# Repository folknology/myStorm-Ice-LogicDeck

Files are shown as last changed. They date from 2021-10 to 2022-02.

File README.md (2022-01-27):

# Ice LogicDeck 
The very first myStorm [Tile](https://github.com/folknology/Tiles) based logic deck, designed around the combination of a powerful STM32 F7 microcontroller fused with a fully configurable Lattice Ice40Hx FPGA.
This forms a modular, heterogeneous embedded development system, it is very much WIP. We will add more documentation soon, you can follow the [live](https://www.twitch.tv/folknology) streaming [narrative](https://www.youtube.com/playlist?list=PLXS9jyX9czzqn4HU2mEmoEFxpgIv1Dvy7) as we develop it, you can follow the evolving [documentation](https://folknology.github.io/myStorm-Ice-LogicDeck/).

#### The 'Deck' based solution is formed by combining multiple [Tiles](https://github.com/folknology/Tiles) and the Ice Logic board carrier
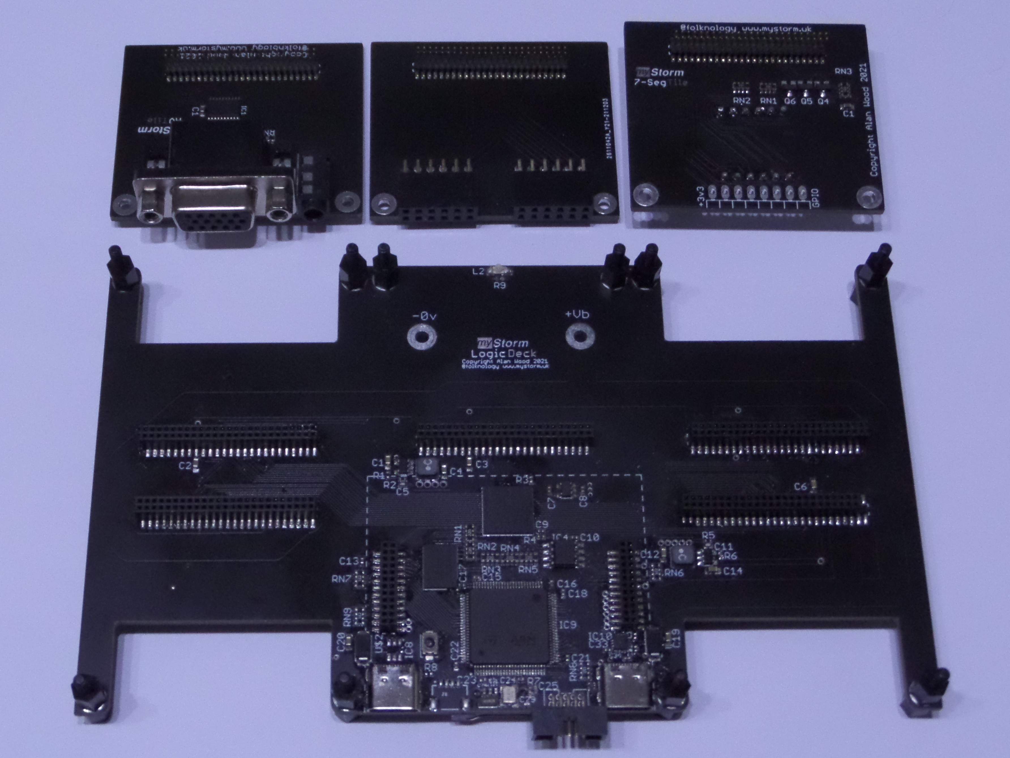
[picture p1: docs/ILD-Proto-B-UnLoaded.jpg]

#### Together these form an Ice LogicDeck solution
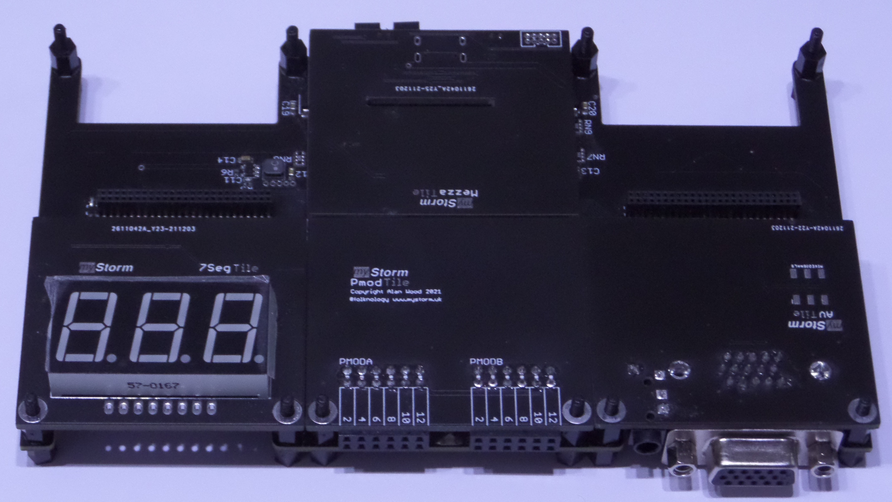
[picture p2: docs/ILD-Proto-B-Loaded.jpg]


### Hardware, development, tooling and software
- [Hardware sources](https://github.com/folknology/myStorm-Ice-LogicDeck/tree/main/Hardware)
- [Firmware sources](https://github.com/folknology/BlackCrab)
- [Examples & board support](https://github.com/folknology/myStorm-Ice-LogicDeck/tree/main/HDL)
- [FPGA HDL/Synthesis, PNR, simulation and formal - Yosys OSS cad suite](https://github.com/YosysHQ/oss-cad-suite-build)

### Further information
- [Tiles](https://github.com/folknology/Tiles)
- [Documentation](https://folknology.github.io/myStorm-Ice-LogicDeck/)
- [Discuss LogicDecks on Discord](https://discord.gg/RCGcgbQNZK)

### OpenSource Design
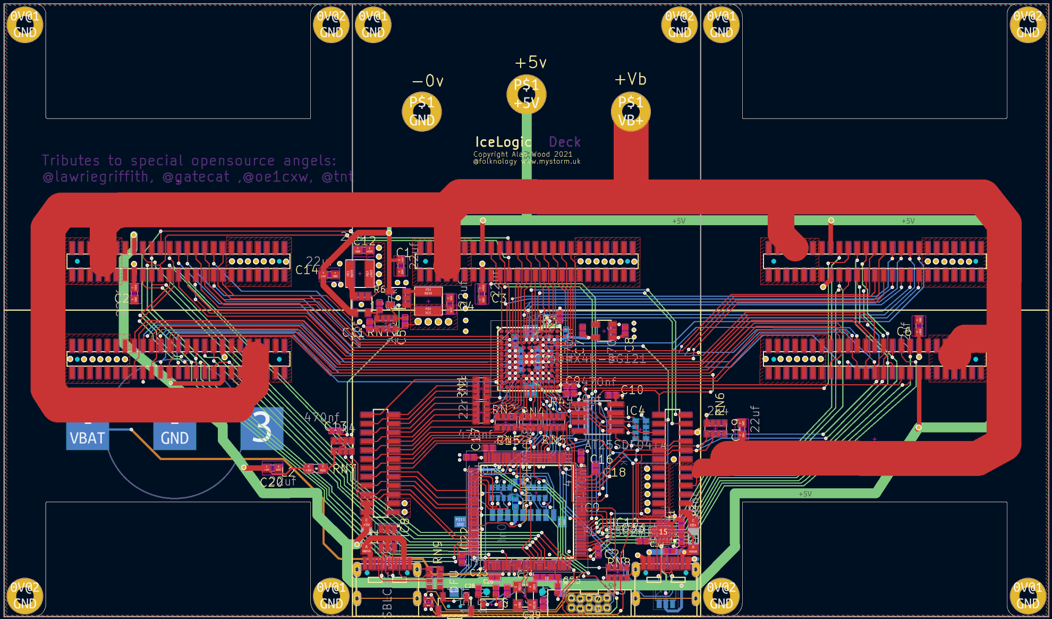
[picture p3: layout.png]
LogicDeck Layout

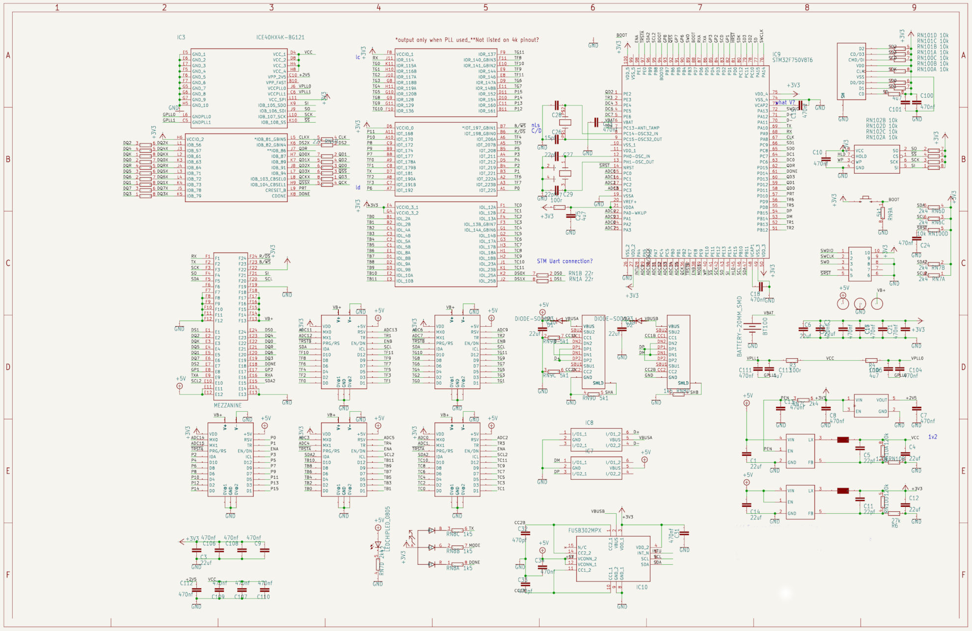
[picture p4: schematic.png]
LogicDeck Schematic


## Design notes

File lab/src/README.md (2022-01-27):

# Lab Notes - Introductions

The documentation is currently under construction and is being developed along with a [live](https://www.twitch.tv/folknology) streaming [narrative](https://www.youtube.com/playlist?list=PLXS9jyX9czzqn4HU2mEmoEFxpgIv1Dvy7) it is very much a work in progress, you can already find some interesting stuff in the examples section.

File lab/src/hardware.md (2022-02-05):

# Ice LogicDeck Hardware
The Ice LogicDeck (ILD) Hardware consists of modular tiles fitted to the main carrier board as required for the given development project. Onboard the main ILD carrier board are the Microcontroller, the FPGA some SPI Flash and connectors.

## Connectivity
The ILD has two Usb connectors, the first is a Usb-C configured as a USB CDC serial device. This can allow programming of the microcontroller, FPGA and flash, along with uart and monitoring features depending on the required mode.

There is a second Usb-C (Usb-PD) Connector which operates as a high Power over Usb 
delivery system operating from 5 to 20 volts in order to be able to power a large range of modular tiles from simple led drivers through to small motor and power-train devices. An auxiliary power supply scheme is also  provided for the more extreme power delivery requirements across the tiles.

## Operating Modes
Mode selection is achieved via the 'Mode' button, if depressed on power up it switches the device into Usb-DFU mode which enables the firmware to be updated from the PC host over Usb. Normal startup places the device into _Development mode_. In development mode the device intelligently listens to Usb traffic for new deck application, FPGA updates whilst concurrently relaying monitor, logging and error information.

A third _Advanced mode_ can be entered pressing the mode button during normal operation. This mode enables additional sub-command modes including _terminal_ , _test_ and  _flash_ for making things permanent or adding ROM data etc.. one can switch back to development mode simple by pressing the mode button once more.

## Status and feedback
There is an RGB led on board which can provide feedback and status of the board's mode and operation. In normal mode this is unlit. if and application or FPGA image is uploaded it will change to red and extinguish on successful completion. If it remains red it will normally be due to either a hardware fault or bad FPGA synthesis. If the mode changes it will illuminate green and change to amber during programing and back to green afterwards, again if it remains amber it will likely be a fault. A third state is possible when the FPGA synthesis drives the blue part of the led for example in a blinky test, the colour will the blink between the either blue and off or blue and the mode colour probably blue and turquoise.

There is also a 1.27mm pitch 10pin, Arm SWD debug socket adjacent to the Usb-PD if you need to debug what is running on the Microcontroller.

In addition to the modular tiles there is an optional Mezzanine Tile which can expand the ILD to add useful features like extra RAM, flash, lcd display and Wi-Fi among other things, check out the [Mezzanine](./mezzanine.md) section for more information of these options.

Setting up Ice LogicDeck - Drivers and firmware:
- [DFU](./dfu_util.md)
- [USB-CDC](./usbcdc.md)
- [Power Delivery](./usbpd.md)

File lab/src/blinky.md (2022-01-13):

# Blinky

## Simple Amaranth blinky using the onboard LED
Simple led blinky example using the blue part of the 
rgb led on the Ice LogicDeck.
```python
{{#include ../../HDL/Amaranth_Examples/Blinky.py}}
```

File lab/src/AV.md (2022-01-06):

# Audio and Video Tile

## VGA VGA Driver and Timings AHDL
```python
{{#include ../../HDL/Amaranth_Examples/Tiles/AAVC_tile.py}}
```

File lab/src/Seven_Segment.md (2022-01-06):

# Seven Segment Tile

## Here is the Top level AHDL Seven_segment.py
Shown below is the Tile example class example we derived from the BlackIce Mx nMigen [examples](https://github.com/lawrie/blackicemx_nmigen_examples/tree/main/seven_segment) for the seven segment tile.
```python
{{#include ../../HDL/Amaranth_Examples/Seven_Segment.py}}
```
## The Seven Segment Tile Driver
The tile driver abstracts the tile resource pinouts handling the low level Hex->7-segment encoding.
```python
{{#include ../../HDL/Amaranth_Examples/Tiles/seven_seg_tile.py}}
```

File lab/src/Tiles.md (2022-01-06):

# Tiles 

## Led test example
We start with a standard tile resource abstraction to work with a protoboard that I have added 12 LEDS t0. We then run some basic Amaranth python HDL to exercise the leds

```python
from amaranth import *
from amaranth.build import *
from IceLogicDeck import *

leds12_tile = [
    Resource("leds12", 0,
            Subsignal("leds", Pins("1 2 3 4 5 6 7 8 9 10 11 12", dir="o", conn=("tile",2)), Attrs(IO_STANDARD="SB_LVCMOS")))
]

class LEDTileTest(Elaboratable):
    def elaborate(self, platform):
        leds12 = Cat([l for l in platform.request("leds12")])
        timer = Signal(38)

        m = Module()
        m.d.sync += timer.eq(timer + 1)
        m.d.comb += leds12.eq(timer[-15:-1])
        return m

if __name__ == "__main__":
    platform = IceLogicDeckPlatform()
    platform.add_resources(leds12_tile)
    platform.build(LEDTileTest(), do_program=True)
```

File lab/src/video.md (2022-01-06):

# Video
## How a VGA frame is divided
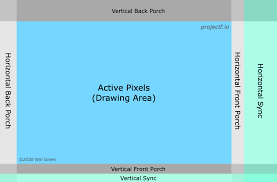
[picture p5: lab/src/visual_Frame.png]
frame

## The VGA Signals
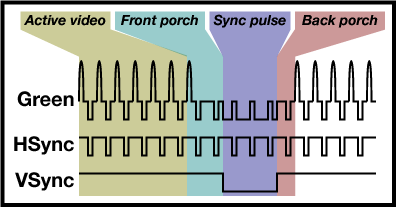
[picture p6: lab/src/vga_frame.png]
signal

## VGA Example AHDL
```python
{{#include ../../HDL/Amaranth_Examples/Audio_Video.py}}
```
## VGA VGA Driver and Timings AHDL
```python
{{#include ../../HDL/Amaranth_Examples/Tiles/vga.py}}
```
[Code we ported from Lawrie](https://github.com/lawrie/blackicemx_nmigen_examples/tree/main/simple_vga) which in turn was built on 
[Guztech's VGA for ULX3s](https://github.com/GuzTech/ulx3s-nmigen-examples/tree/master/dvi)

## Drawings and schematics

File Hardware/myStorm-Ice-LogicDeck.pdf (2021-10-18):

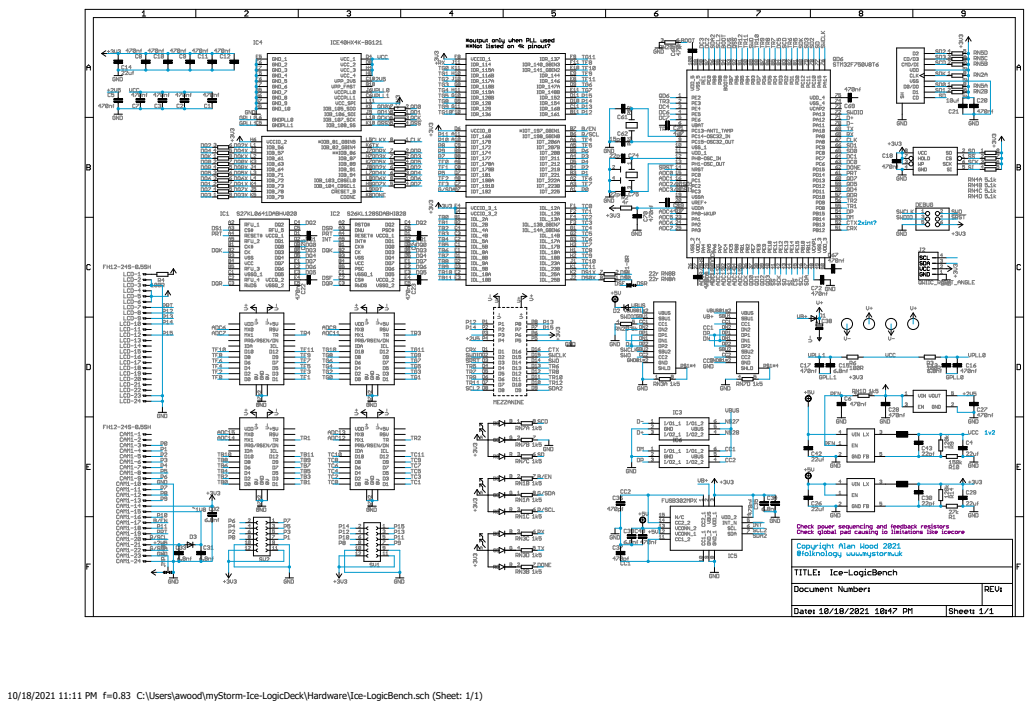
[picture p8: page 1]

10/18/2021 11:11 PM f=0.83 C:\Users\awood\myStorm-Ice-LogicDeck\Hardware\Ice-LogicBench.sch (Sheet: 1/1)

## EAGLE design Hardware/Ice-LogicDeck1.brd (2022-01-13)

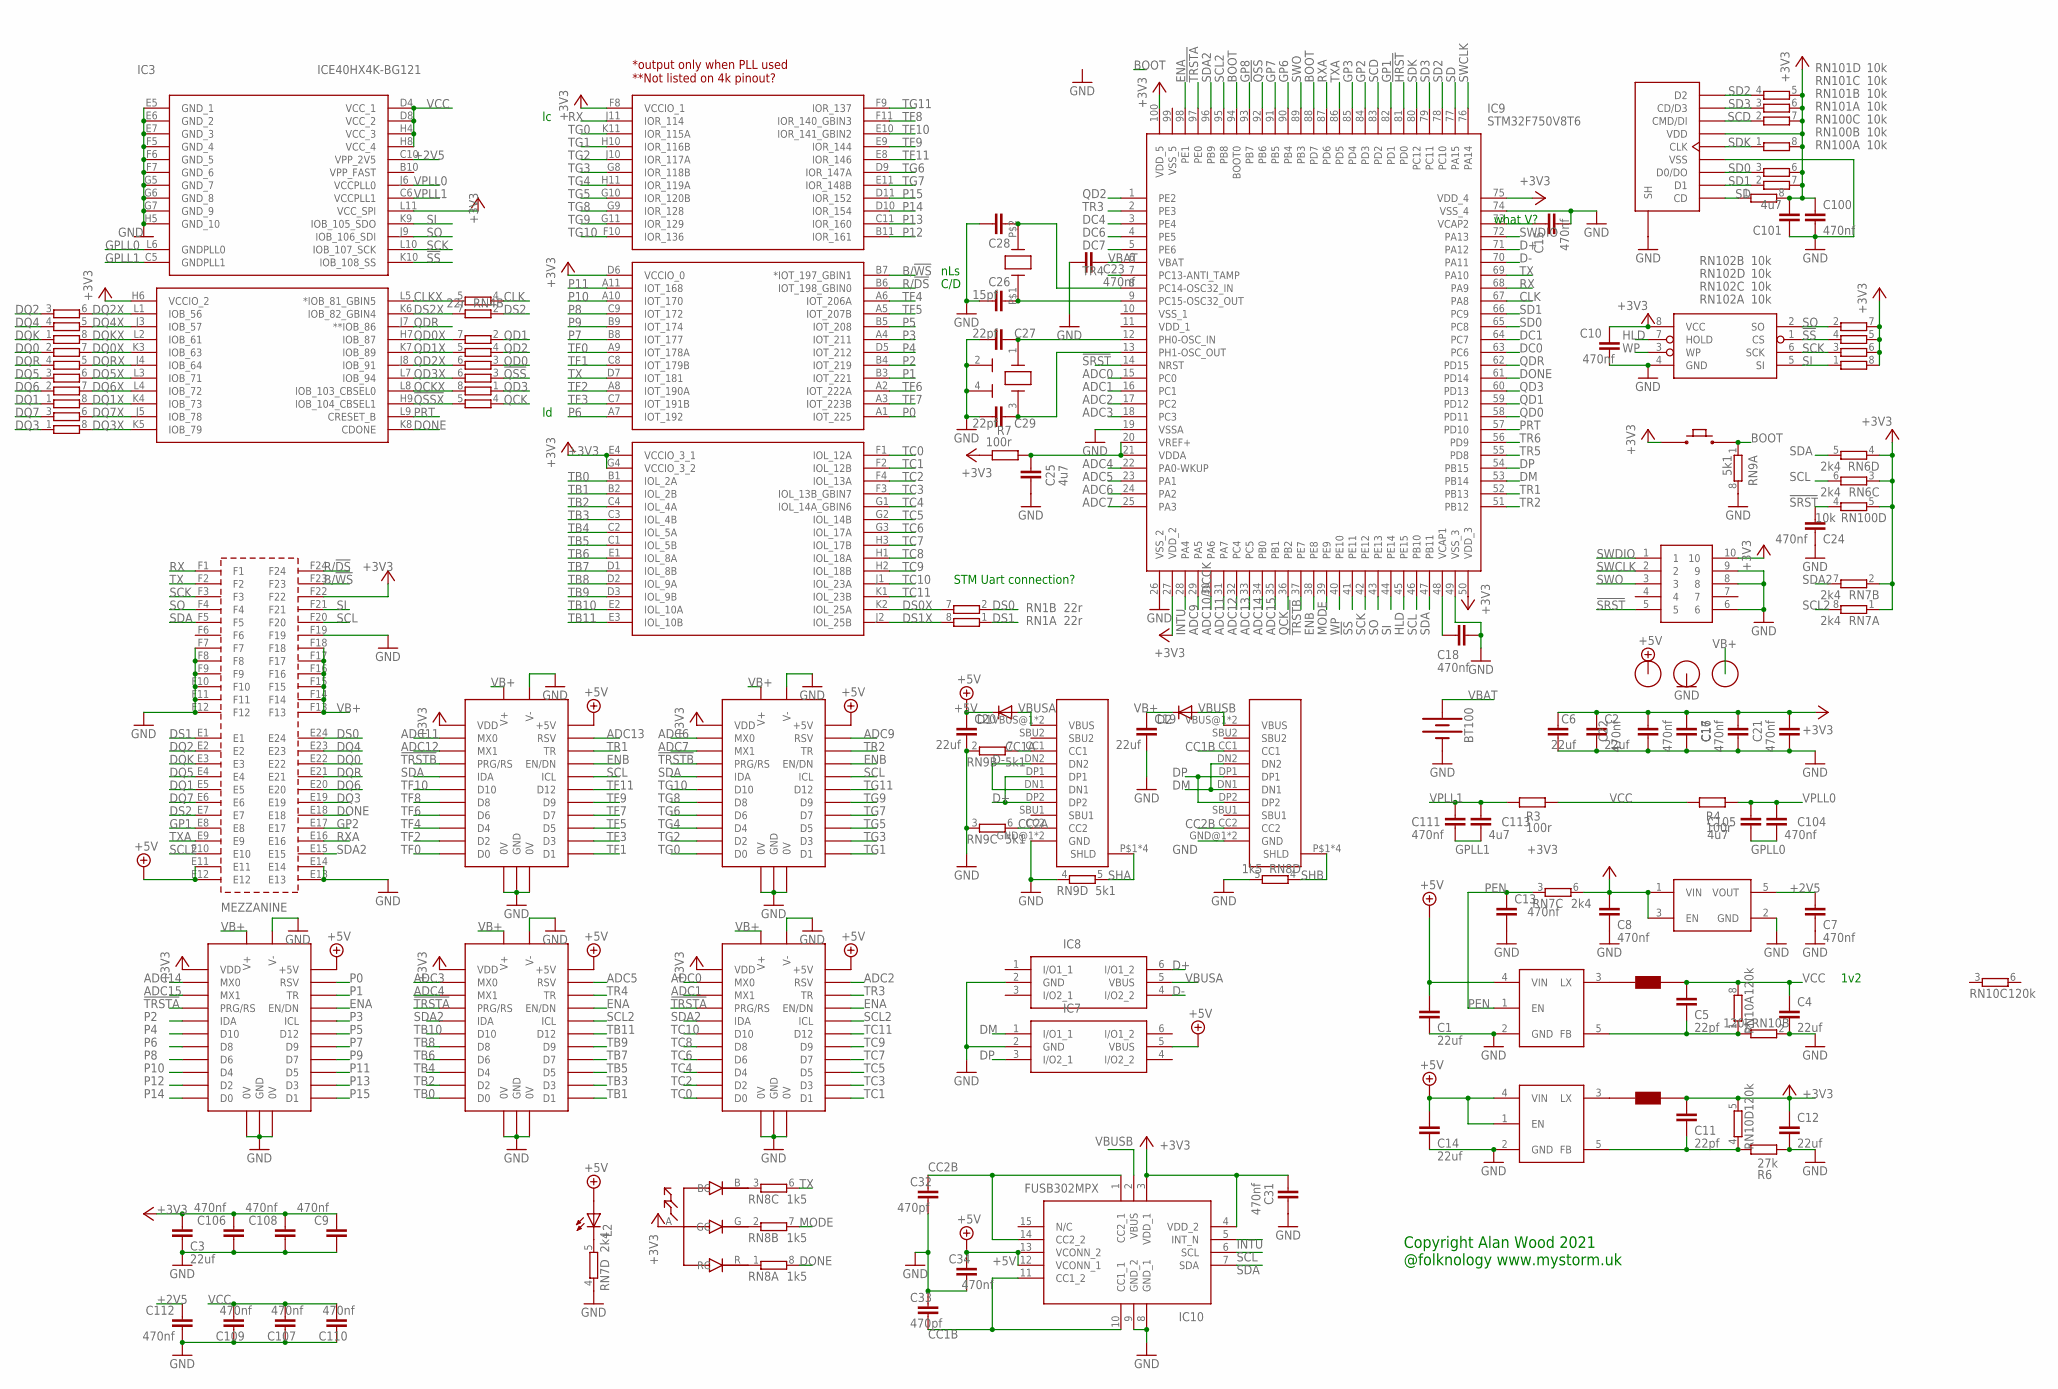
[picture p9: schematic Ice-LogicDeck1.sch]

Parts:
BT100: BATTERY-20MM_SMD; BATTCON_20MM
C1, C2, C3, C4, C6, C12, C14, C19, C20: 22uf; C0603
C5, C11, C27, C29: 22pf; C0402
C7, C8, C9, C10, C13, C15, C16, C17, C18, C21, C22, C23, C24, C31, C34, C100, C104, C106, C107, C108, C109, C110, C111, C112: 470nf; C0402
C25, C101, C105, C113: 4u7; C0402
C26, C28: 15pf; C0402
C32, C33: 470pf; C0402
CN1, CN2: USB-C-16; USB-C
CN3: 2X5-HEADER; 1.27-2X5-HEADER
D1, D2: DIODE-SOD123; SOD123
DFU: 4X3-RA-BUTTON
H1, H3, H4: HOLE2.5MM-LARGE; 2M5-LARGE
I1, I2: NRS4018; NRC4018
IC1, IC5: AP3429/A; TSOP-5/SOT23-5
IC2: NCP114; TSOP-5/SOT23-5
IC3: ICE40HX4K-BG121; BGA121C80P11X11_900X900X110
IC4: AT25SDF041A; SOIC-8-NARROW
IC7, IC8: USBLC6-2SC6; SOT95P280X145-6N
IC9: STM32F750V8T6; QFP50P1600X1600X160-100N
IC10: FUSB302MPX; QFN50P250X250X80-15N
L1: RGB_LED; RGB_LED_IMM
L2: LEDCHIPLED_0805; CHIPLED_0805
MEZZANINE: HYPER-TILECARRIER; HYPER-TILE
R3, R4, R7: 100r; R0402
R6: 27k; R0402
RN1, RN2, RN3, RN4, RN5: 22r; EXB38V
RN6, RN7: 2k4; EXB38V
RN8: 1k5; EXB38V
RN9: 5k1; EXB38V
RN10: 120k; EXB38V
RN100, RN101, RN102: 10k; EXB38V
SD100: TF-15X15; SDCARD
TILE1, TILE2, TILE3, TILE4, TILE5: UTILE_LPCARRIER_SMD_MALE_1.27; UTILE_LP
Y1: 12MZ; CRYSTAL-3.2X2.5
Y2: FC-135; FC135

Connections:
!HRST: IC9.81 (PD0)
!QSS: IC9.92 (PB6), RN4.3 (1)
!QSSX: IC3.H9 (IOB_104_CBSEL1), RN5.5 (2)
!SRST: C24.2, CN3.5, IC9.14 (NRST), RN100.4 (1)
!SS: IC3.K10 (IOB_108_SS), IC4.1 (CS), IC9.41 (PE11), RN102.4 (1)
!TRSTA: IC9.97 (PE0), TILE1.P$15 (PRG/RS), TILE2.P$15 (PRG/RS), TILE4.P$15 (PRG/RS)
!TRSTB: IC9.37 (PE7), TILE3.P$15 (PRG/RS), TILE5.P$15 (PRG/RS)
+2V5: C7.2, C112.1, IC2.5 (VOUT), IC3.C10 (VPP_2V5)
+3V3: C2.1, C3.2, C6.2, C8.2, C9.1, C10.1, C11.2, C12.1, C16.2, C17.2, C21.2, C22.2, C31.2, C100.1, C101.2, C106.1, C108.1, CN3.10, DFU.P$1, I2.P$2, IC2.1 (VIN), IC2.3 (EN), IC3.D6 (VCCIO_0), IC3.E4 (VCCIO_3_1), IC3.F8 (VCCIO_1), IC3.G4 (VCCIO_3_2), IC3.H6 (VCCIO_2), IC3.L11 (VCC_SPI), IC4.8 (VCC), IC9.27 (VDD_2), IC9.50 (VDD_3), IC9.75 (VDD_4), IC9.100 (VDD_5), IC10.3 (VDD_1), IC10.4 (VDD_2), L1.A (ANODE), MEZZANINE.F22, R7.2, RN6.3 (1), RN6.4 (1), RN7.1, RN7.2 (1), RN7.6 (2), RN10.5 (2), RN100.5 (2), RN100.6 (2), RN100.7 (2), RN100.8 (2), RN101.5 (2), RN101.6 (2), RN101.7 (2), RN101.8 (2), RN102.5 (2), RN102.6 (2), RN102.7 (2), RN102.8 (2), SD100.P$6 (VDD), TILE1.P$18 (VDD), TILE2.P$18 (VDD), TILE3.P$18 (VDD), TILE4.P$18 (VDD), TILE5.P$18 (VDD)
+5V: C1.2, C14.2, C20.1, C34.2, D1.C, H1.P$1, IC1.4 (VIN), IC5.1 (EN), IC5.4 (VIN), IC7.5 (VBUS), IC10.12 (VCONN_1), IC10.13 (VCONN_2), L2.A, MEZZANINE.E11, MEZZANINE.E12, TILE1.P$43 (+5V), TILE2.P$43 (+5V), TILE3.P$43 (+5V), TILE4.P$43 (+5V), TILE5.P$43 (+5V)
ADC0: IC9.15 (PC0), TILE4.P$17 (MX0)
ADC1: IC9.16 (PC1), TILE4.P$16 (MX1)
ADC2: IC9.17 (PC2), TILE4.P$42 (RSV)
ADC3: IC9.18 (PC3), TILE1.P$17 (MX0)
ADC4: IC9.22 (PA0-WKUP), TILE1.P$16 (MX1)
ADC5: IC9.23 (PA1), TILE1.P$42 (RSV)
ADC6: IC9.24 (PA2), TILE5.P$17 (MX0)
ADC7: IC9.25 (PA3), TILE5.P$16 (MX1)
ADC9: IC9.29 (PA5), TILE5.P$42 (RSV)
ADC10/DCCK: IC9.30 (PA6)
ADC11: IC9.31 (PA7), TILE3.P$17 (MX0)
ADC12: IC9.32 (PC4), TILE3.P$16 (MX1)
ADC13: IC9.33 (PC5), TILE3.P$42 (RSV)
ADC14: IC9.34 (PB0), TILE2.P$17 (MX0)
ADC15: IC9.35 (PB1), TILE2.P$16 (MX1)
B/!WS: IC3.B7 (*IOT_197_GBIN1), MEZZANINE.F23
BOOT: DFU.P$2, IC9.88 (PD7), IC9.94 (BOOT0), RN9.1
CC1A: CN1.CC1, RN9.7 (2)
CC1B: C33.1, CN2.CC1, IC10.10 (CC1_1), IC10.11 (CC1_2)
CC2A: CN1.CC2, RN9.6 (2)
CC2B: C32.2, CN2.CC2, IC10.1 (CC2_1), IC10.14 (CC2_2)
CLK: IC9.67 (PA8), RN3.4 (1)
CLKX: IC3.L5 (*IOB_81_GBIN5), RN3.5 (2)
D+: CN1.DP1, CN1.DP2, IC8.6 (I/O1_2), IC9.71 (PA12)
D-: CN1.DN1, CN1.DN2, IC8.4 (I/O2_2), IC9.70 (PA11)
DC0: IC9.63 (PC6)
DC1: IC9.64 (PC7)
DC4: IC9.3 (PE4)
DC6: IC9.4 (PE5)
DC7: IC9.5 (PE6)
DM: CN2.DN1, CN2.DN2, IC7.1 (I/O1_1), IC9.53 (PB14)
DONE: IC3.K8 (CDONE), IC9.61 (PD14), MEZZANINE.E18, RN8.8 (2)
DP: CN2.DP1, CN2.DP2, IC7.3 (I/O2_1), IC9.54 (PB15)
DQ0: MEZZANINE.E22, RN2.2 (1)
DQ0X: IC3.K3 (IOB_63), RN2.7 (2)
DQ1: MEZZANINE.E5, RN3.1
DQ1X: IC3.K4 (IOB_73), RN3.8 (2)
DQ2: MEZZANINE.E2, RN1.3 (1)
DQ2X: IC3.L1 (IOB_56), RN1.6 (2)
DQ3: MEZZANINE.E19, RN4.1
DQ3X: IC3.K5 (IOB_79), RN4.8 (2)
DQ4: MEZZANINE.E23, RN1.4 (1)
DQ4X: IC3.J3 (IOB_57), RN1.5 (2)
DQ5: MEZZANINE.E4, RN2.3 (1)
DQ5X: IC3.L3 (IOB_71), RN2.6 (2)
DQ6: MEZZANINE.E20, RN3.2 (1)
DQ6X: IC3.L4 (IOB_72), RN3.7 (2)
DQ7: MEZZANINE.E6, RN3.3 (1)
DQ7X: IC3.J5 (IOB_78), RN3.6 (2)
DQK: MEZZANINE.E3, RN2.1
DQKX: IC3.L2 (IOB_61), RN2.8 (2)
DQR: MEZZANINE.E21, RN2.4 (1)
DQRX: IC3.J4 (IOB_64), RN2.5 (2)
DS0: MEZZANINE.E24, RN1.2 (1)
DS0X: IC3.K2 (IOL_25A), RN1.7 (2)
DS1: MEZZANINE.E1, RN1.1
DS1X: IC3.J2 (IOL_25B), RN1.8 (2)
DS2: MEZZANINE.E7, RN4.2 (1)
DS2X: IC3.K6 (IOB_82_GBIN4), RN4.7 (2)
ENA: IC9.98 (PE1), TILE1.P$40 (EN/DN), TILE2.P$40 (EN/DN), TILE4.P$40 (EN/DN)
ENB: IC9.38 (PE8), TILE3.P$40 (EN/DN), TILE5.P$40 (EN/DN)
GND: BT100.2 (-), C1.1, C2.2, C3.1, C4.2, C6.1, C7.1, C8.1, C9.2, C10.2, C12.2, C13.2, C14.1, C15.2, C16.1, C17.1, C18.1, C19.2, C20.2, C21.1, C22.1, C23.2, C24.1, C25.2, C26.1, C27.1, C28.1, C29.1, C31.1, C32.1, C33.2, C34.1, C100.2, C101.1, C106.2, C107.1, C108.2, C109.1, C110.1, C112.2, CN1.GND@1 (GND), CN1.GND@2 (GND), CN2.GND@1 (GND), CN2.GND@2 (GND), CN3.6, CN3.8, CN3.9, H3.P$1, IC1.2 (GND), IC2.2 (GND), IC3.E5 (GND_1), IC3.E6 (GND_2), IC3.E7 (GND_3), IC3.F5 (GND_4), IC3.F6 (GND_5), IC3.F7 (GND_6), IC3.G5 (GND_7), IC3.G6 (GND_8), IC3.G7 (GND_9), IC3.H5 (GND_10), IC4.4 (GND), IC5.2 (GND), IC7.2 (GND), IC8.2 (GND), IC9.19 (VSSA), IC9.26 (VSS_2), IC9.49 (VSS_3), IC9.74 (VSS_4), IC10.8 (GND_1), IC10.9 (GND_2), MEZZANINE.E13, MEZZANINE.E14, MEZZANINE.F7, MEZZANINE.F8, MEZZANINE.F9, MEZZANINE.F10, MEZZANINE.F11, MEZZANINE.F12, MEZZANINE.F19, R6.2, RN7.4 (1), RN8.5 (2), RN9.2 (1), RN9.3 (1), RN9.4 (1), RN9.8 (2), RN10.2 (1), SD100.P$4 (VSS), SD100.P$10 (SH), SD100.P$11 (SH), SD100.P$12 (SH), SD100.P$13 (SH), TILE1.0V@1 (0V), TILE1.0V@2 (0V), TILE1.P$1 (V-), TILE1.P$2 (V-), TILE1.P$3 (V-), TILE1.P$4 (V-), TILE1.P$5 (V-), TILE1.P$6 (V-), TILE1.P$7 (GND), TILE1.P$26 (V-), TILE1.P$27 (V-), TILE1.P$28 (V-), TILE1.P$29 (V-), TILE1.P$30 (V-), TILE1.P$31 (V-), TILE1.P$32 (GND), TILE2.0V@1 (0V), TILE2.0V@2 (0V), TILE2.P$1 (V-), TILE2.P$2 (V-), TILE2.P$3 (V-), TILE2.P$4 (V-), TILE2.P$5 (V-), TILE2.P$6 (V-), TILE2.P$7 (GND), TILE2.P$26 (V-), TILE2.P$27 (V-), TILE2.P$28 (V-), TILE2.P$29 (V-), TILE2.P$30 (V-), TILE2.P$31 (V-), TILE2.P$32 (GND), TILE3.0V@1 (0V), TILE3.0V@2 (0V), TILE3.P$1 (V-), TILE3.P$2 (V-), TILE3.P$3 (V-), TILE3.P$4 (V-), TILE3.P$5 (V-), TILE3.P$6 (V-), TILE3.P$7 (GND), TILE3.P$26 (V-), TILE3.P$27 (V-), TILE3.P$28 (V-), TILE3.P$29 (V-), TILE3.P$30 (V-), TILE3.P$31 (V-), TILE3.P$32 (GND), TILE4.0V@1 (0V), TILE4.0V@2 (0V), TILE4.P$1 (V-), TILE4.P$2 (V-), TILE4.P$3 (V-), TILE4.P$4 (V-), TILE4.P$5 (V-), TILE4.P$6 (V-), TILE4.P$7 (GND), TILE4.P$26 (V-), TILE4.P$27 (V-), TILE4.P$28 (V-), TILE4.P$29 (V-), TILE4.P$30 (V-), TILE4.P$31 (V-), TILE4.P$32 (GND), TILE5.0V@1 (0V), TILE5.0V@2 (0V), TILE5.P$1 (V-), TILE5.P$2 (V-), TILE5.P$3 (V-), TILE5.P$4 (V-), TILE5.P$5 (V-), TILE5.P$6 (V-), TILE5.P$7 (GND), TILE5.P$26 (V-), TILE5.P$27 (V-), TILE5.P$28 (V-), TILE5.P$29 (V-), TILE5.P$30 (V-), TILE5.P$31 (V-), TILE5.P$32 (GND), Y1.2 (GND), Y1.4 (GND)
GP1: IC9.82 (PD1), MEZZANINE.E8
GP2: IC9.84 (PD3), MEZZANINE.E17
GP3: IC9.85 (PD4)
GP6: IC9.90 (PB4)
GP7: IC9.91 (PB5)
GP8: IC9.93 (PB7)
GPLL0: C104.1, C105.1, IC3.L6 (GNDPLL0)
GPLL1: C111.1, C113.1, IC3.C5 (GNDPLL1)
HLD: IC4.7 (HOLD), IC9.45 (PE15)
INTU: IC9.28 (PA4), IC10.5 (INT_N)
MODE: IC9.39 (PE9), RN8.7 (2)
unnamed: L2.C, RN7.5 (2)
unnamed: L1.G (GC), RN8.2 (1)
unnamed: L1.R (RC), RN8.1
unnamed: L1.B (BC), RN8.3 (1)
unnamed: C29.2, IC9.13 (PH1-OSC_OUT), Y1.3 (X2)
unnamed: C27.2, IC9.12 (PH0-OSC_IN), Y1.1 (X1)
unnamed: C26.2, IC9.9 (PC15-OSC32_OUT), Y2.P$1 (X1)
unnamed: C28.2, IC9.8 (PC14-OSC32_IN), Y2.P$2 (X2)
unnamed: C15.1, IC9.73 (VCAP2)
unnamed: C11.1, IC5.5 (FB), R6.1, RN10.4 (1)
unnamed: I2.P$1, IC5.3 (LX)
unnamed: C18.2, IC9.48 (VCAP1)
unnamed: C25.1, IC9.20 (VREF+), IC9.21 (VDDA), R7.1
unnamed: C5.1, IC1.5 (FB), RN10.1, RN10.7 (2)
unnamed: I1.P$1, IC1.3 (LX)
P0: IC3.A1 (IOT_225), TILE2.P$42 (RSV)
P1: IC3.B3 (IOT_221), TILE2.P$41 (TR)
P2: IC3.B4 (IOT_219), TILE2.P$14 (IDA)
P3: IC3.A4 (IOT_211), TILE2.P$39 (ICL)
P4: IC3.D5 (IOT_212), TILE2.P$13 (D10)
P5: IC3.B5 (IOT_208), TILE2.P$38 (D12)
P6: IC3.A7 (IOT_192), TILE2.P$12 (D8)
P7: IC3.B8 (IOT_177), TILE2.P$37 (D9)
P8: IC3.C9 (IOT_172), TILE2.P$11 (D6)
P9: IC3.B9 (IOT_174), TILE2.P$36 (D7)
P10: IC3.A10 (IOT_170), TILE2.P$10 (D4)
P11: IC3.A11 (IOT_168), TILE2.P$35 (D5)
P12: IC3.B11 (IOR_161), TILE2.P$9 (D2)
P13: IC3.C11 (IOR_160), TILE2.P$34 (D3)
P14: IC3.D10 (IOR_154), TILE2.P$8 (D0)
P15: IC3.D11 (IOR_152), TILE2.P$33 (D1)
PEN: C13.1, IC1.1 (EN), RN7.3 (1)
PRT: IC3.L9 (CRESET_B), IC9.57 (PD10)
QCK: IC9.36 (PB2), RN5.4 (1)
QCKX: IC3.L8 (IOB_103_CBSEL0), RN5.8 (2)
QD0: IC9.58 (PD11), RN5.3 (1)
QD0X: IC3.H7 (IOB_87), RN5.7 (2)
QD1: IC9.59 (PD12), RN5.2 (1)
QD1X: IC3.K7 (IOB_89), RN4.5 (2)
QD2: IC9.1 (PE2), RN4.4 (1)
QD2X: IC3.J8 (IOB_91), RN5.6 (2)
QD3: IC9.60 (PD13), RN5.1
QD3X: IC3.L7 (IOB_94), RN4.6 (2)
QDR: IC3.J7 (**IOB_86), IC9.62 (PD15)
R/!DS: IC3.B6 (IOT_198_GBIN0), MEZZANINE.F24
RX: IC3.J11 (IOR_114), IC9.68 (PA9), MEZZANINE.F1
RXA: IC9.87 (PD6), MEZZANINE.E16
SCD: IC9.83 (PD2), RN101.2 (1), SD100.P$7 (CMD/DI)
SCK: IC3.L10 (IOB_107_SCK), IC4.6 (SCK), IC9.42 (PE12), MEZZANINE.F3, RN102.3 (1)
SCL: IC9.46 (PB10), IC10.6 (SCL), MEZZANINE.F20, RN6.6 (2), TILE3.P$39 (ICL), TILE5.P$39 (ICL)
SCL2: IC9.95 (PB8), MEZZANINE.E10, RN7.8 (2), TILE1.P$39 (ICL), TILE4.P$39 (ICL)
SD: IC9.77 (PA15), RN100.1, SD100.P$1 (CD)
SD0: IC9.65 (PC8), RN100.3 (1), SD100.P$3 (D0/DO)
SD1: IC9.66 (PC9), RN100.2 (1), SD100.P$2 (D1)
SD2: IC9.78 (PC10), RN101.4 (1), SD100.P$9 (D2)
SD3: IC9.79 (PC11), RN101.3 (1), SD100.P$8 (CD/D3)
SDA: IC9.47 (PB11), IC10.7 (SDA), MEZZANINE.F5, RN6.5 (2), TILE3.P$14 (IDA), TILE5.P$14 (IDA)
SDA2: IC9.96 (PB9), MEZZANINE.E15, RN7.7 (2), TILE1.P$14 (IDA), TILE4.P$14 (IDA)
SDK: IC9.80 (PC12), RN101.1, SD100.P$5 (CLK)
SHA: CN1.P$1 (SHLD), CN1.P$2 (SHLD), CN1.P$3 (SHLD), CN1.P$4 (SHLD), RN9.5 (2)
SHB: CN2.P$1 (SHLD), CN2.P$2 (SHLD), CN2.P$3 (SHLD), CN2.P$4 (SHLD), RN8.4 (1)
SI: IC3.K9 (IOB_105_SDO), IC4.5 (SI), IC9.44 (PE14), MEZZANINE.F21, RN102.1
SO: IC3.J9 (IOB_106_SDI), IC4.2 (SO), IC9.43 (PE13), MEZZANINE.F4, RN102.2 (1)
SWCLK: CN3.2, IC9.76 (PA14)
SWDIO: CN3.1, IC9.72 (PA13)
SWO: CN3.3, IC9.89 (PB3)
TB0: IC3.B1 (IOL_2A), TILE1.P$8 (D0)
TB1: IC3.B2 (IOL_2B), TILE1.P$33 (D1)
TB2: IC3.C4 (IOL_4A), TILE1.P$9 (D2)
TB3: IC3.C3 (IOL_4B), TILE1.P$34 (D3)
TB4: IC3.C2 (IOL_5A), TILE1.P$10 (D4)
TB5: IC3.C1 (IOL_5B), TILE1.P$35 (D5)
TB6: IC3.E1 (IOL_8A), TILE1.P$11 (D6)
TB7: IC3.D1 (IOL_8B), TILE1.P$36 (D7)
TB8: IC3.D2 (IOL_9A), TILE1.P$12 (D8)
TB9: IC3.D3 (IOL_9B), TILE1.P$37 (D9)
TB10: IC3.E2 (IOL_10A), TILE1.P$13 (D10)
TB11: IC3.E3 (IOL_10B), TILE1.P$38 (D12)
TC0: IC3.F1 (IOL_12A), TILE4.P$8 (D0)
TC1: IC3.F2 (IOL_12B), TILE4.P$33 (D1)
TC2: IC3.F4 (IOL_13A), TILE4.P$9 (D2)
TC3: IC3.F3 (IOL_13B_GBIN7), TILE4.P$34 (D3)
TC4: IC3.G1 (IOL_14A_GBIN6), TILE4.P$10 (D4)
TC5: IC3.G2 (IOL_14B), TILE4.P$35 (D5)
TC6: IC3.G3 (IOL_17A), TILE4.P$11 (D6)
TC7: IC3.H3 (IOL_17B), TILE4.P$36 (D7)
TC8: IC3.H1 (IOL_18A), TILE4.P$12 (D8)
TC9: IC3.H2 (IOL_18B), TILE4.P$37 (D9)
TC10: IC3.J1 (IOL_23A), TILE4.P$13 (D10)
TC11: IC3.K1 (IOL_23B), TILE4.P$38 (D12)
TF0: IC3.A9 (IOT_178A), TILE3.P$8 (D0)
TF1: IC3.C8 (IOT_179B), TILE3.P$33 (D1)
TF2: IC3.A8 (IOT_190A), TILE3.P$9 (D2)
TF3: IC3.C7 (IOT_191B), TILE3.P$34 (D3)
TF4: IC3.A6 (IOT_206A), TILE3.P$10 (D4)
TF5: IC3.A5 (IOT_207B), TILE3.P$35 (D5)
TF6: IC3.A2 (IOT_222A), TILE3.P$11 (D6)
TF7: IC3.A3 (IOT_223B), TILE3.P$36 (D7)
TF8: IC3.F11 (IOR_140_GBIN3), TILE3.P$12 (D8)
TF9: IC3.E9 (IOR_144), TILE3.P$37 (D9)
TF10: IC3.E10 (IOR_141_GBIN2), TILE3.P$13 (D10)
TF11: IC3.E8 (IOR_146), TILE3.P$38 (D12)
TG0: IC3.K11 (IOR_115A), TILE5.P$8 (D0)
TG1: IC3.H10 (IOR_116B), TILE5.P$33 (D1)
TG2: IC3.J10 (IOR_117A), TILE5.P$9 (D2)
TG3: IC3.G8 (IOR_118B), TILE5.P$34 (D3)
TG4: IC3.H11 (IOR_119A), TILE5.P$10 (D4)
TG5: IC3.G10 (IOR_120B), TILE5.P$35 (D5)
TG6: IC3.D9 (IOR_147A), TILE5.P$11 (D6)
TG7: IC3.E11 (IOR_148B), TILE5.P$36 (D7)
TG8: IC3.G9 (IOR_128), TILE5.P$12 (D8)
TG9: IC3.G11 (IOR_129), TILE5.P$37 (D9)
TG10: IC3.F10 (IOR_136), TILE5.P$13 (D10)
TG11: IC3.F9 (IOR_137), TILE5.P$38 (D12)
TR1: IC9.52 (PB13), TILE3.P$41 (TR)
TR2: IC9.51 (PB12), TILE5.P$41 (TR)
TR3: IC9.2 (PE3), TILE4.P$41 (TR)
TR4: IC9.7 (PC13-ANTI_TAMP), TILE1.P$41 (TR)
TR5: IC9.55 (PD8)
TR6: IC9.56 (PD9)
TX: IC3.D7 (IOT_181), IC9.69 (PA10), MEZZANINE.F2, RN8.6 (2)
TXA: IC9.86 (PD5), MEZZANINE.E9
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

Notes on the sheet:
Copyright Alan Wood 2021 @folknology www.mystorm.uk
1v2
nLs
C/D
STM Uart connection?
what V?

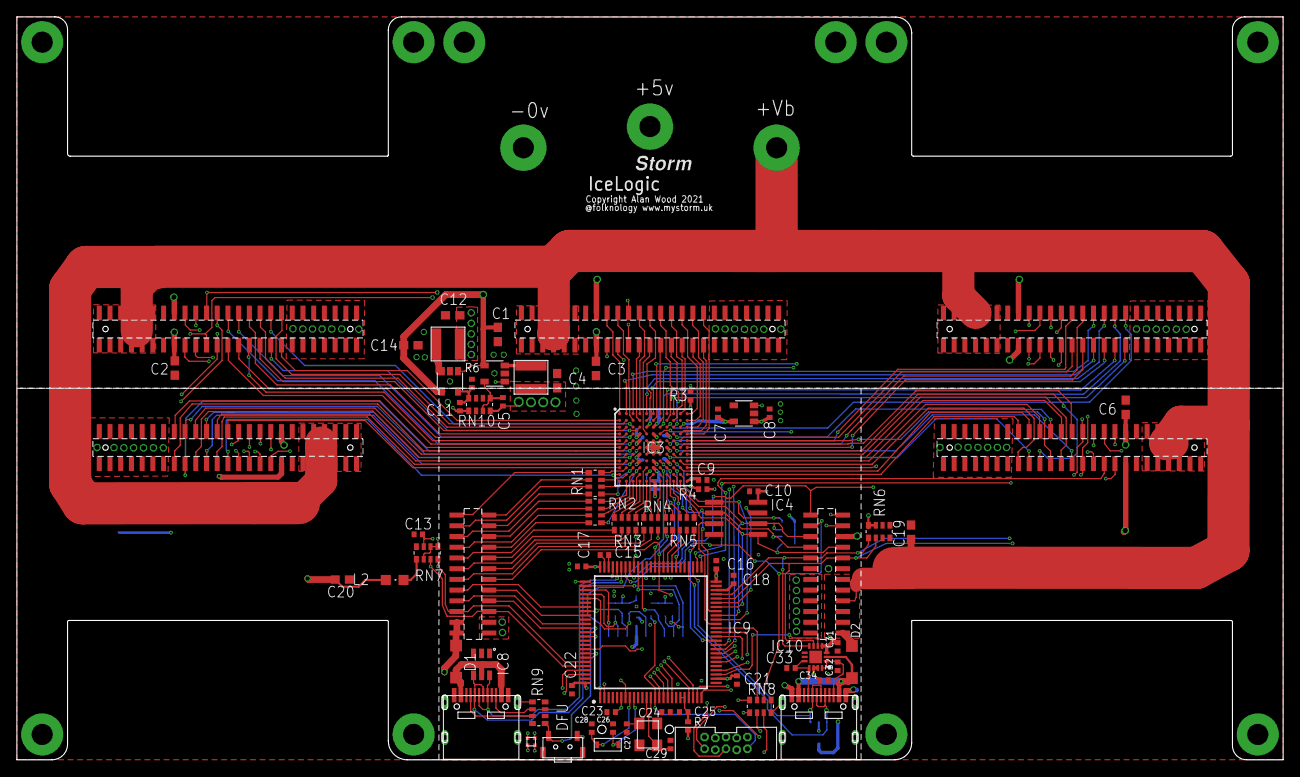
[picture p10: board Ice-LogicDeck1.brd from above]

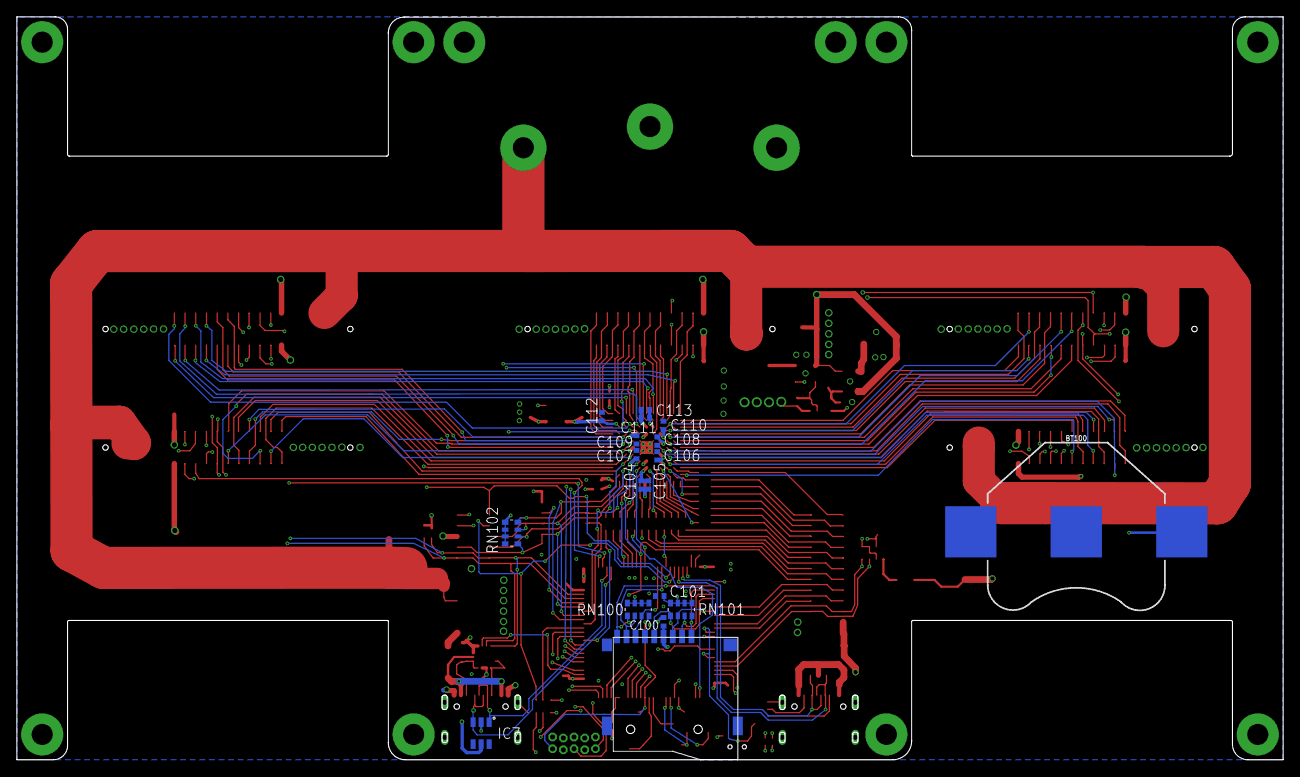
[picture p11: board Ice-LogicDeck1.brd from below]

Board: 4 copper layers, 150.0 x 88.0 mm, 94 parts (18 on the bottom side), 200 nets.

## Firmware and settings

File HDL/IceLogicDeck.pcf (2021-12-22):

set_io clk L5

# Tile 1
set_io -nowarn tile1[0] B1
set_io -nowarn  tile1[1] B2
set_io -nowarn  tile1[2] C4
set_io -nowarn  tile1[3] C3
set_io -nowarn  tile1[4] C2
set_io -nowarn  tile1[5] C1
set_io -nowarn  tile1[6] E1
set_io -nowarn  tile1[7] D1
set_io -nowarn  tile1[8] D2
set_io -nowarn  tile1[9] D3
set_io -nowarn  tile1[10] E2
set_io -nowarn  tile1[11] E3

# Tile 2 (super tile)
set_io tile2[0] D10 # p14
set_io tile2[1] D11 # p15
set_io tile2[2] B11 # p12
set_io tile2[3] C11 # p13
set_io tile2[4] A10 # p10
set_io tile2[5] A11 # p11
set_io tile2[6] C9 # p9
set_io tile2[7] B9 # p8
set_io tile2[8] A7 # p7
set_io tile2[9] B8 # p6
set_io tile2[10] D5 # p5
set_io tile2[11] B5 # p4
set_io -nowarn  sda B4 # p3
set_io -nowarn  scl A4 # p2
set_io -nowarn  rsv A1 # p1
set_io -nowarn  tr B3 # p0


# Tile 3
set_io -nowarn  tile3[0] A9
set_io -nowarn  tile3[1] C8
set_io -nowarn  tile3[2] A8
set_io -nowarn  tile3[3] C7
set_io -nowarn  tile3[4] A6
set_io -nowarn  tile3[5] A5
set_io -nowarn  tile3[6] A2
set_io -nowarn  tile3[7] A3
set_io -nowarn  tile3[8] F11
set_io -nowarn  tile3[9] E9
set_io -nowarn  tile3[10] E10
set_io -nowarn  tile3[11] E8

# Tile 4
set_io -nowarn  tile4[0] F1
set_io -nowarn  tile4[1] F2
set_io -nowarn  tile4[2] F4
set_io -nowarn  tile4[3] F3
set_io -nowarn  tile4[4] G1
set_io -nowarn  tile4[5] G2
set_io -nowarn  tile4[6] G3
set_io -nowarn  tile4[7] H3
set_io -nowarn  tile4[8] H1
set_io -nowarn  tile4[9] H2
set_io -nowarn  tile4[10] J1
set_io -nowarn  tile4[11] K1

# Tile 5
set_io -nowarn  tile5[0] K11
set_io -nowarn  tile5[1] H10
set_io -nowarn  tile5[2] J10
set_io -nowarn  tile5[3] G8
set_io -nowarn  tile5[4] H11
set_io -nowarn  tile5[5] G10
set_io -nowarn  tile5[6] D9
set_io -nowarn  tile5[7] E11
set_io -nowarn  tile5[8] G9
set_io -nowarn  tile5[9] G11
set_io -nowarn  tile5[10] F10
set_io -nowarn  tile5[11] F9

# HyperRam
set_io -nowarn  dq[0] K3
set_io -nowarn  dq[1] K4
set_io -nowarn  dq[2] L1
set_io -nowarn  dq[3] K5
set_io -nowarn  dq[4] J3
set_io -nowarn  dq[5] L3
set_io -nowarn  dq[6] L4
set_io -nowarn  dq[7] J5
set_io -nowarn  dqk L2
set_io -nowarn  dqr J4
set_io -nowarn  ds0 K6

# QsPie
set_io -nowarn  qd[0] J8
set_io -nowarn  qd[1] H7
set_io -nowarn  qd[2] K7
set_io -nowarn  qd[3] L8
set_io -nowarn  qck H9
set_io -nowarn  qss L7
set_io -nowarn  qdr J7

# SPI
set_io -nowarn  si K9
set_io -nowarn  so J9
set_io -nowarn  sck L10
set_io -nowarn  ss L7

# Uart
set_io -nowarn  tx K2
set_io -nowarn  rx J2

# Mezzanine
set_io -nowarn  mt0 J11 # lc
set_io -nowarn  g_mt1 D7 # ld
set_io -nowarn  b_ws B7 # nls
set_io -nowarn  r_ds B6 # lc/d

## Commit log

2021-10-17 Added initial versions of eagle cad files and pdf schematic
    [Ice-LogicBench.brd, Ice-LogicBench.sch]
2021-10-17 Added schematic and layout previews
2021-10-17 Added readme tile link
    [Ice-LogicBench.brd]
2021-10-17 Juggled some pins to improve IO frm @tnt suggestion
    [Ice-LogicBench.brd, Ice-LogicBench.sch]
2021-10-18 Added series resistors for fast data lines and a cs jumper to alloy hyperflash to be swapped by 2nd hyperram
    [Ice-LogicBench.brd, Ice-LogicBench.sch]
2021-10-18 Cleaned up schematic and updated previews
    [Ice-LogicBench.brd, Ice-LogicBench.sch]
2021-10-18 REarranged TG/F pinouts for pait matches updated schematic and previews
    [Ice-LogicBench.brd, Ice-LogicBench.sch]
2021-10-19 Improved the routing a little
    [Ice-LogicBench.brd]
2021-12-22 Added PCF and Amaranth Board files
2021-12-22 Changed from generic led array naming to tile array naming
2021-12-22 Added Amaranth board file for Ice LogicDeck along with simple proto led test
2022-01-06 Temporarily added book by disabling the git ignore until I cal work out the continuous Integration required
    [Ice-LogicBench.brd, Ice-LogicBench.sch]
2022-01-13 Added blinky and a experimental docs dir
    [Ice-LogicDeck1.brd, Ice-LogicDeck1.sch]
2022-01-27 Corrected Yosy cad suite links
2022-01-27 Corrected Yosys cad suite links
2022-01-27 Updated Images for layout and schematic
2022-01-27 Updated schematic

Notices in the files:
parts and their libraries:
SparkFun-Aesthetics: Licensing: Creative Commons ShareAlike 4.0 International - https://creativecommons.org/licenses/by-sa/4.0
